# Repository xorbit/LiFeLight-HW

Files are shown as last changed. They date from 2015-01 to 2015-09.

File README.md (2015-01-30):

LiFeLight hardware
==================

[LiFePO4wered/USB]: http://lifepo4wered.com
[MSP430G2210]: http://www.ti.com/product/msp430g2210
[CCS]: http://www.ti.com/tool/ccstudio
[Github project]: https://github.com/xorbit/LiFeLight
[OSH Park]: https://oshpark.com/shared_projects/UGFRTknj

This is the Eagle source project for the LiFeLight demo board hardware.  LiFeLight is a board developed as a soldering kit for the Maker Faire, that can be added to a [LiFePO4wered/USB][] module to create a programmable touch flashlight.  It's a good example of getting decent functionality with minimal, low cost hardware.  It has the following subsystems:

Touch sensor
------------

The touch sensor is a simple PCB pad.  All touch detection functionality is implemented in software, using a simple interrupt driven charge/discharge scheme.

LED booster
-----------

To have high light output using various colors of LED (including white), using a supply voltage that can be as low as 2V, a simple booster circuit was implemented.  The software drives the LED output at ~100kHz.  Yes, the LED has to be mounted "backwards", because it is powered from the inductor's flyback voltage.

Microcontroller
---------------

All LiFeLight functionality is implemented in software that runs on a low cost [MSP430G2210][] microcontroller.  The software was implemented using [CCS][].  The source code can be found in this [Github project][].

Ordering
--------

If you don't want to deal with doing it yourself, the PCBs can be ordered conveniently from [OSH Park][].

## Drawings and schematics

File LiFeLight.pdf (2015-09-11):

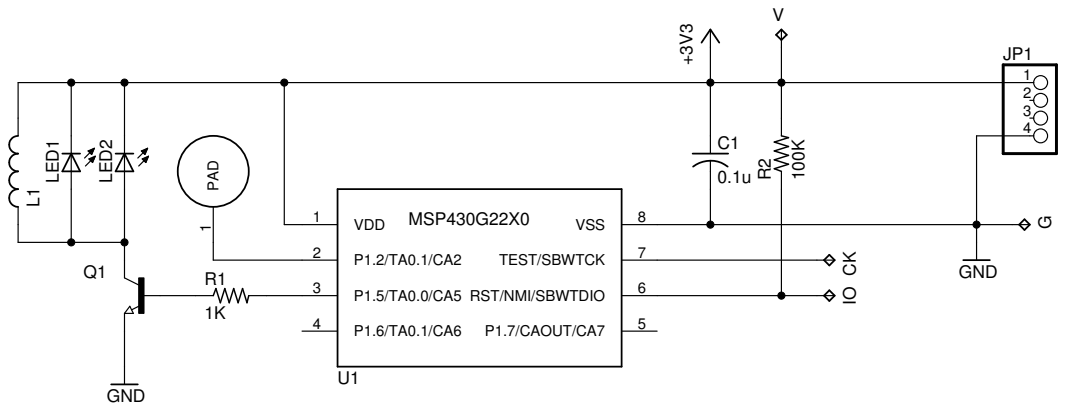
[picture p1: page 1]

Document Number: | REV:

Date: 1/9/15 6:22 PM | Sheet: 1/1

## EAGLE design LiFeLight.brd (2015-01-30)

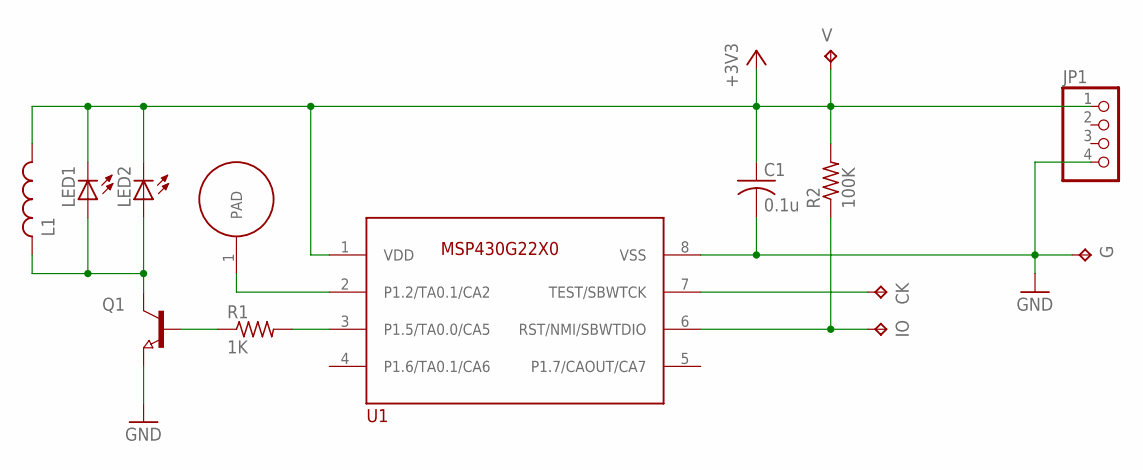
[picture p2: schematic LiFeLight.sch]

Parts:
C1: 0.1u; C0805K
CK: TPB1,27; B1,27
G: TPB1,27; B1,27
IO: TPB1,27; B1,27
JP1: PINHD-1X4; 1X04
L1: L-USL2825P; L2825P
LED1: LEDSQR2X5; LED2X5
LED2: LEDSMT1206; 1206
Q1: NPN-TRANSISTOR_SOT23; SOT23
R1: 1K; R0805
R2: 100K; R0805
TOUCH1: TOUCHPAD8MM; TOUCHPAD8
U1: MSP430G22X0; SO08
V: TPB1,27; B1,27

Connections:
+3V3: C1.1, JP1.1, L1.1, LED1.K (C), LED2.C, R2.2, U1.1 (VDD), V.TP
GND: C1.2, G.TP, JP1.4, Q1.2 (E), U1.8 (VSS)
unnamed: L1.2, LED1.A, LED2.A, Q1.3 (C)
unnamed: IO.TP, R2.1, U1.6 (RST/NMI/SBWTDIO)
unnamed: CK.TP, U1.7 (TEST/SBWTCK)
unnamed: Q1.1 (B), R1.1
unnamed: TOUCH1.1, U1.2 (P1.2/TA0.1/CA2)
unnamed: R1.2, U1.3 (P1.5/TA0.0/CA5)

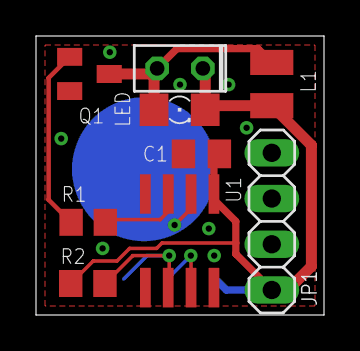
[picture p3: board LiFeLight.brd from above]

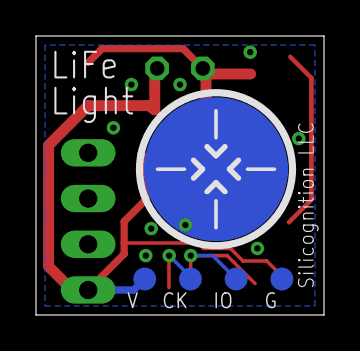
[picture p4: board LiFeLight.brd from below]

Board: 2 copper layers, 16.0 x 15.5 mm, 14 parts (5 on the bottom side), 8 nets.
